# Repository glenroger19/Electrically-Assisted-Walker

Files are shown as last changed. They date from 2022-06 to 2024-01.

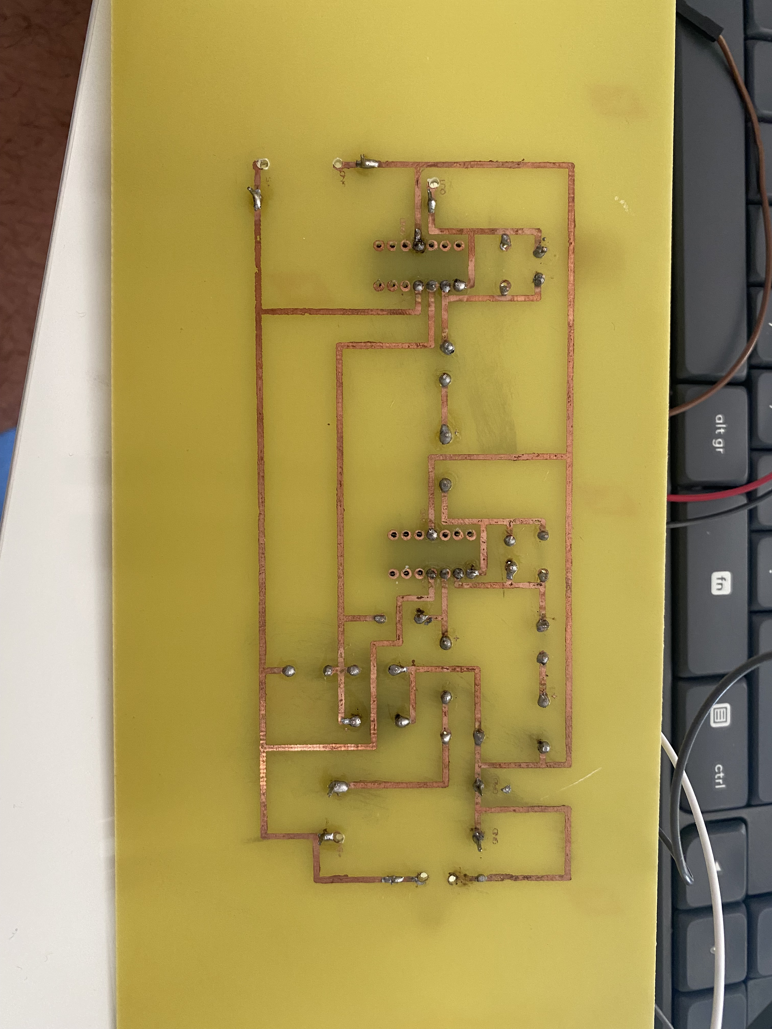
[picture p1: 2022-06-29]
Amplifier/Amplifier Back.jpg

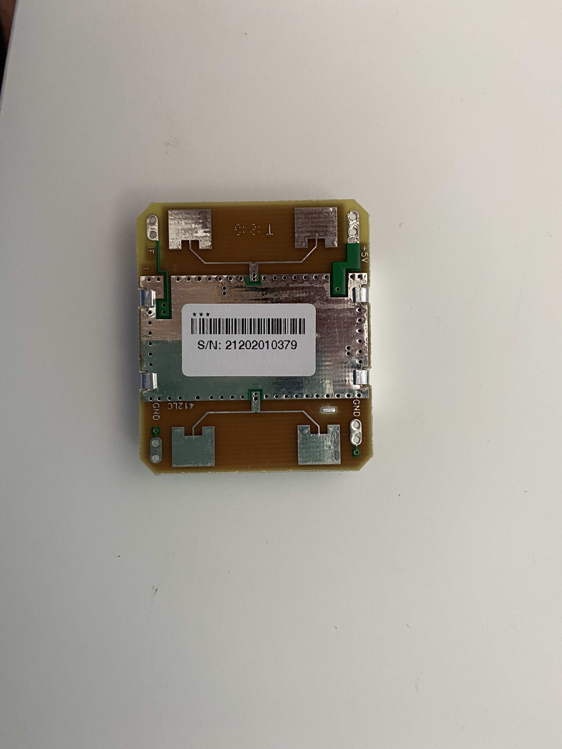
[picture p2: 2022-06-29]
Sensor/Sensor Front.jpg

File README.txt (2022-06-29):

Hi everyone, 

Welcome to this project that deals with setting up an electrically assisted walker.

Step 1 : Choose an AgilSense HB100 Doppler Sensor.
Step 2 : Amplify the signal out of the sensor which is a voltage between 0 and 4 mV.
Step 3 : Measure the voltage after amplifier which is between 0 to 4 V.
Step 4 : Use a DAC (Digital to Analog Converter) and use the code to measure the speed.
Step 5 : Perform a simulation of the motor with different resisting torque.
Step 6 : Carry out a simulation of the motor speed control and choose a corrector.
Step 7 : Vary the gain of a proportional corrector and the gain of an integral corrector to have an accurate, fast and stable system.

Thanks for your interest and hope to colaborate soon!

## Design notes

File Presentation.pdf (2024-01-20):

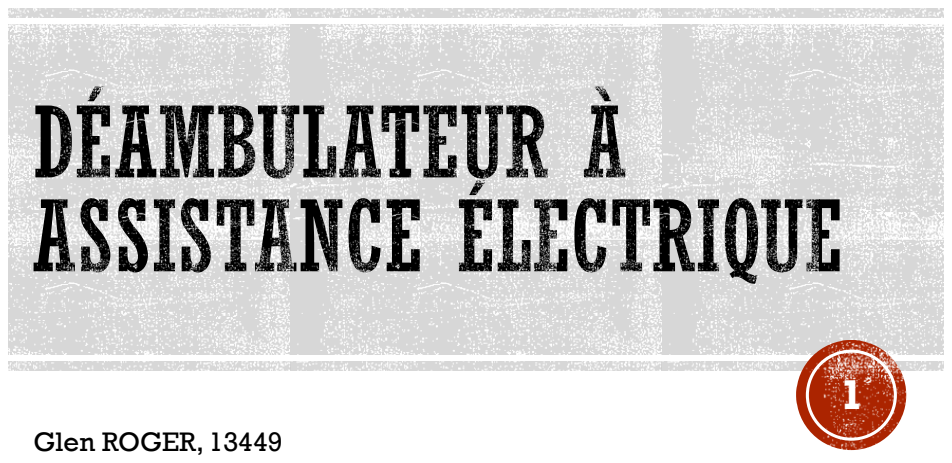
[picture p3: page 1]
Glen ROGER, 13449

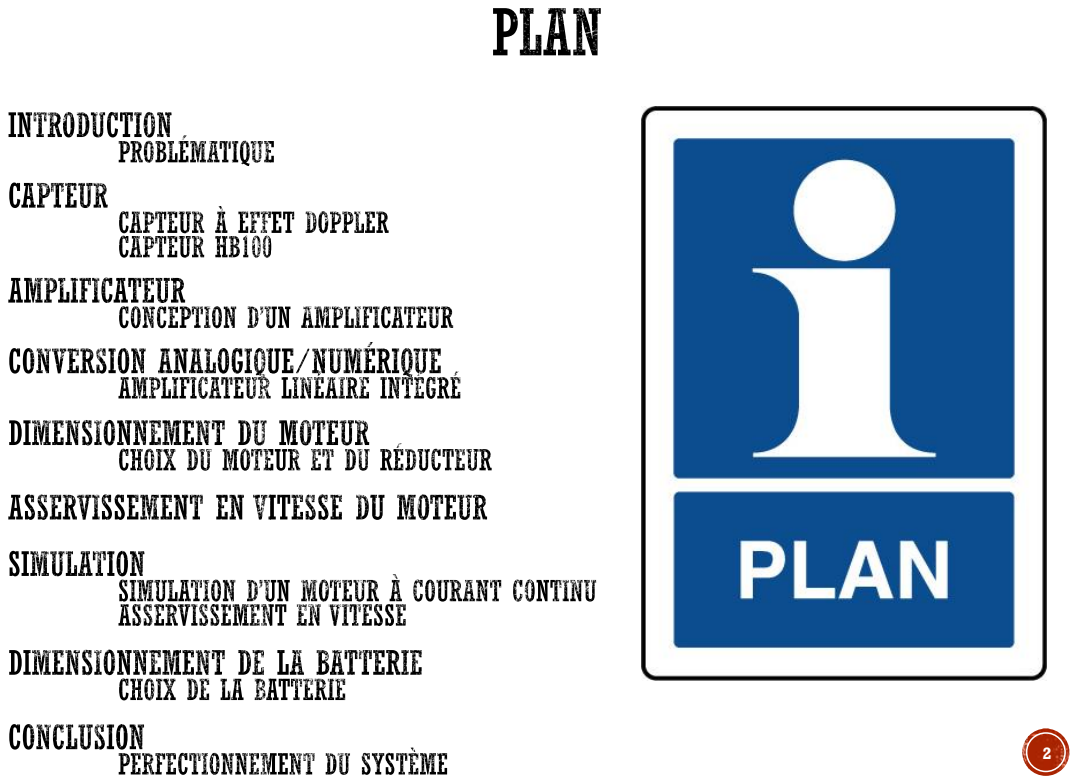
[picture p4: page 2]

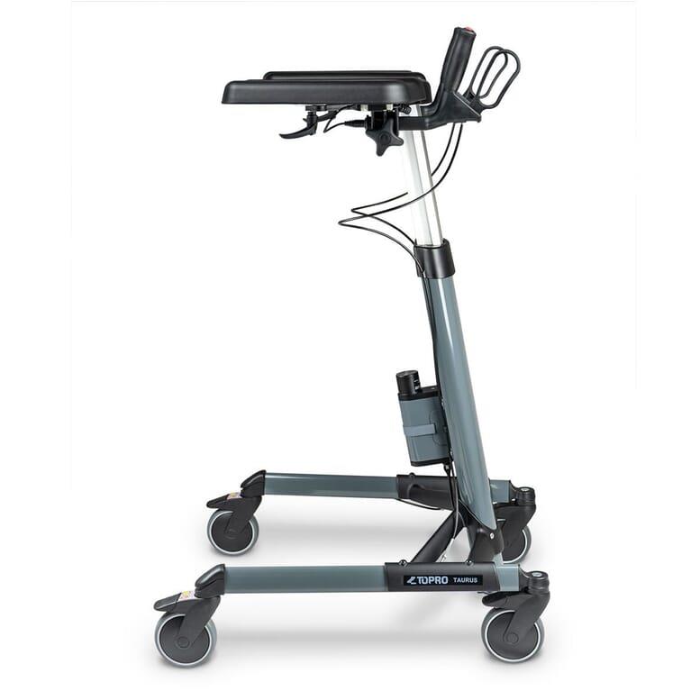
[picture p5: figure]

Source : Déambulateur Topro Taurus

3

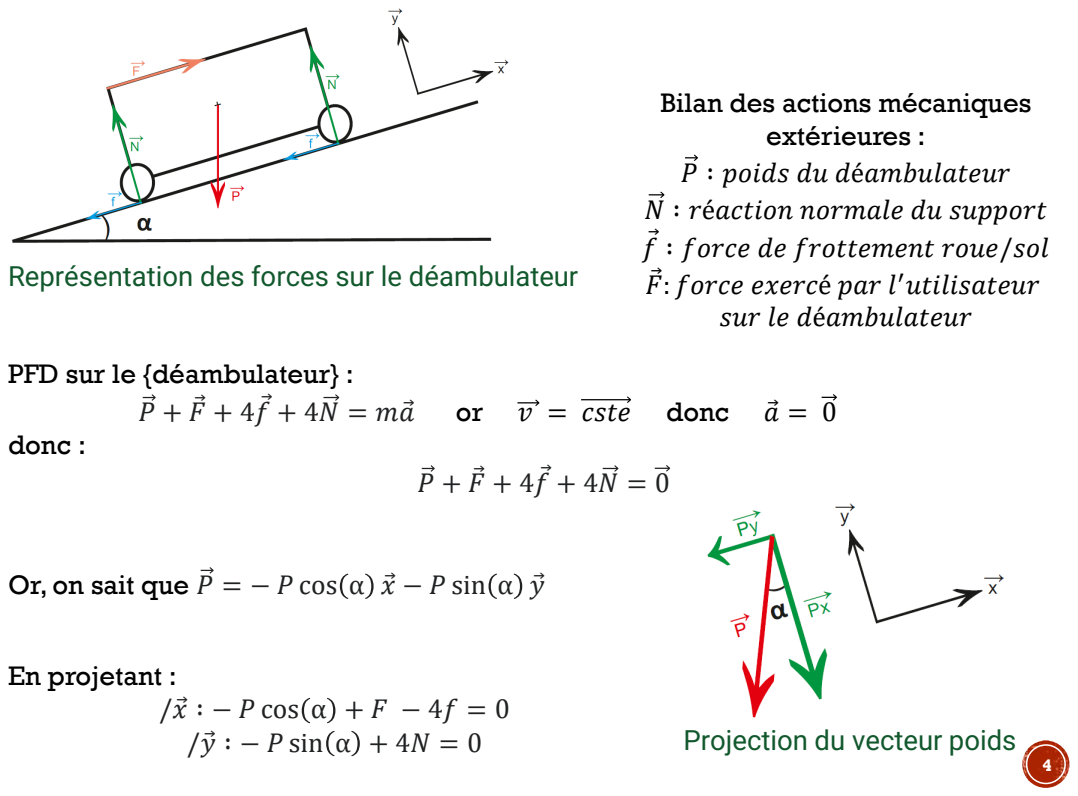
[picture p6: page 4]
extérieures : P ∶ poids du déambulateur N ∶ réaction normale du support f; ′utilisateur sur le déambulateur; v = cste; donc; donc :; Ԧ − P sin α y; En projetant : /x; ∶ − P cos α + F − 4f = 0 /y; ∶ − P sin α + 4N = 0

Bilan des actions mécaniques

∶ force de frottement roue/sol
: force exercé par l

Représentation des forces sur le déambulateur

PFD sur le {déambulateur} :

Or, on sait que P = − P cos α x

Projection du vecteur poids

Application numérique :
m = 30 kg
g = 9,81 m/s
α = 20°
μ = 0,5

On a donc :
F = 30 ∗ 9,81 ∗ cos 20 + 4 ∗ 0,5 ∗ 30 ∗ 9,81 ∗ sin 20 F = 477,9 N
Soit F ≈ 48,73 kg

On a alors :
F = P cos α + 4μ ∗ P ∗ sin α F = mg ∗ cos α + 4μ ∗ mg ∗ sin α

Or :
f = μN
avec μ ∶ coefficient de glissement Et :
N = P sin(α)
Donc :
4f = 4μ ∗ P ∗ sin(α)

5

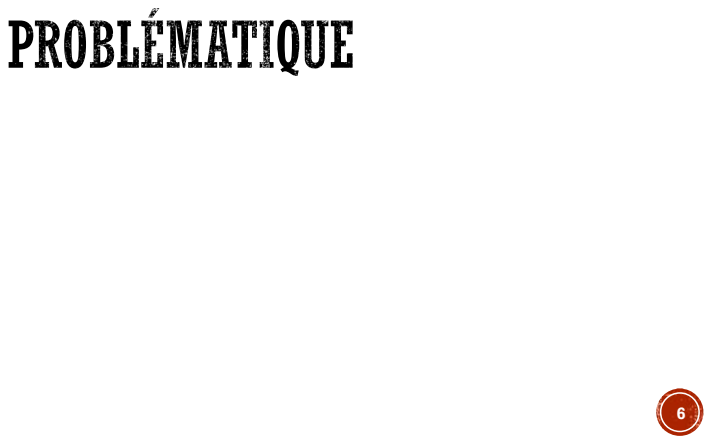
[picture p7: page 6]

7

Dispositif :
grandeur physique | tension, intensité,…

Types de capteur :

Capteurs analogiques

Capteurs logiques

Capteurs numériques

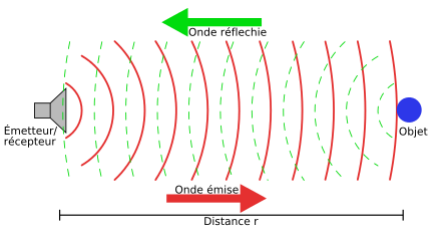
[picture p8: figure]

Source : http://www.lyc-mansart-st-cyr.ac-versailles.fr/IMG/pdf/tpevincent.pdf

8

Doppler Equation:
Fd = 2V

Ft
c

cosϴ

Avec :
Fd = Fréquence Doppler
V = Vitesse de la cible
Ft = Fréquence de transmission c = vitesse de la lumière
ϴ = Angle entre la cible et l

′axe du module

Et on a d’après le datasheet : Ft = 10,525 GHz

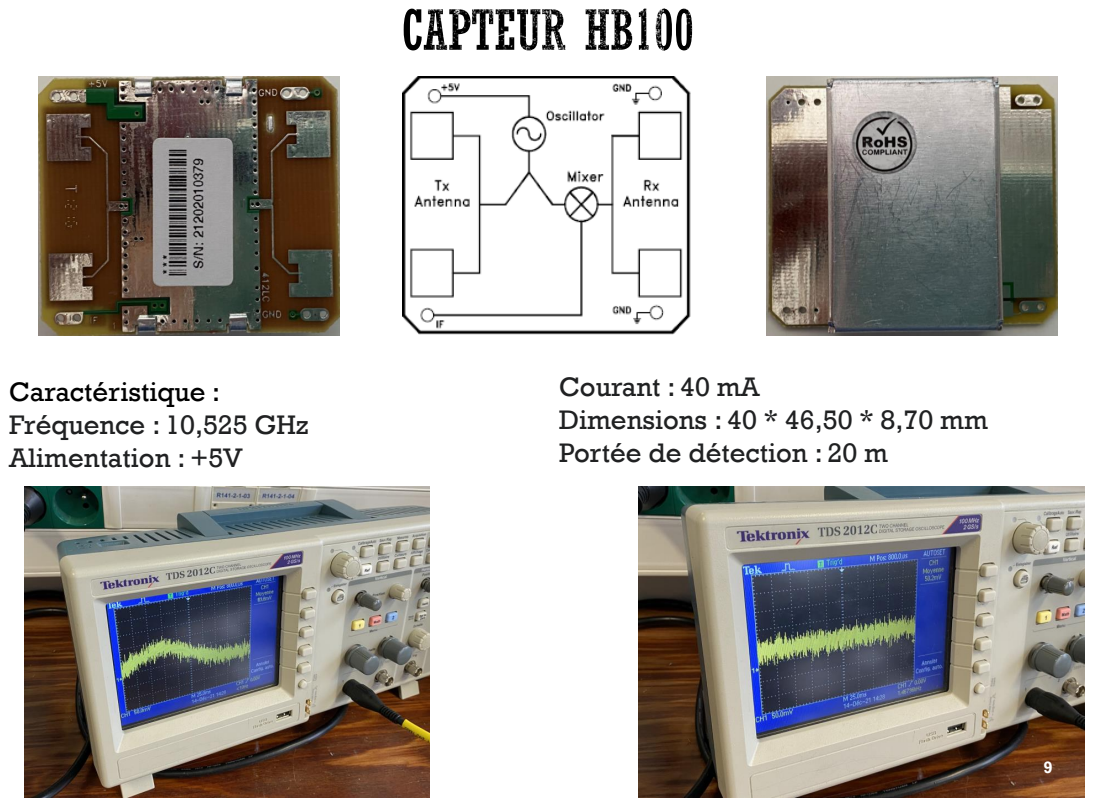
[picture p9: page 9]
Caractéristique : Fréquence : 10,525 GHz Alimentation : +5V

Courant : 40 mA
Dimensions : 40 * 46,50 * 8,70 mm
Portée de détection : 20 m

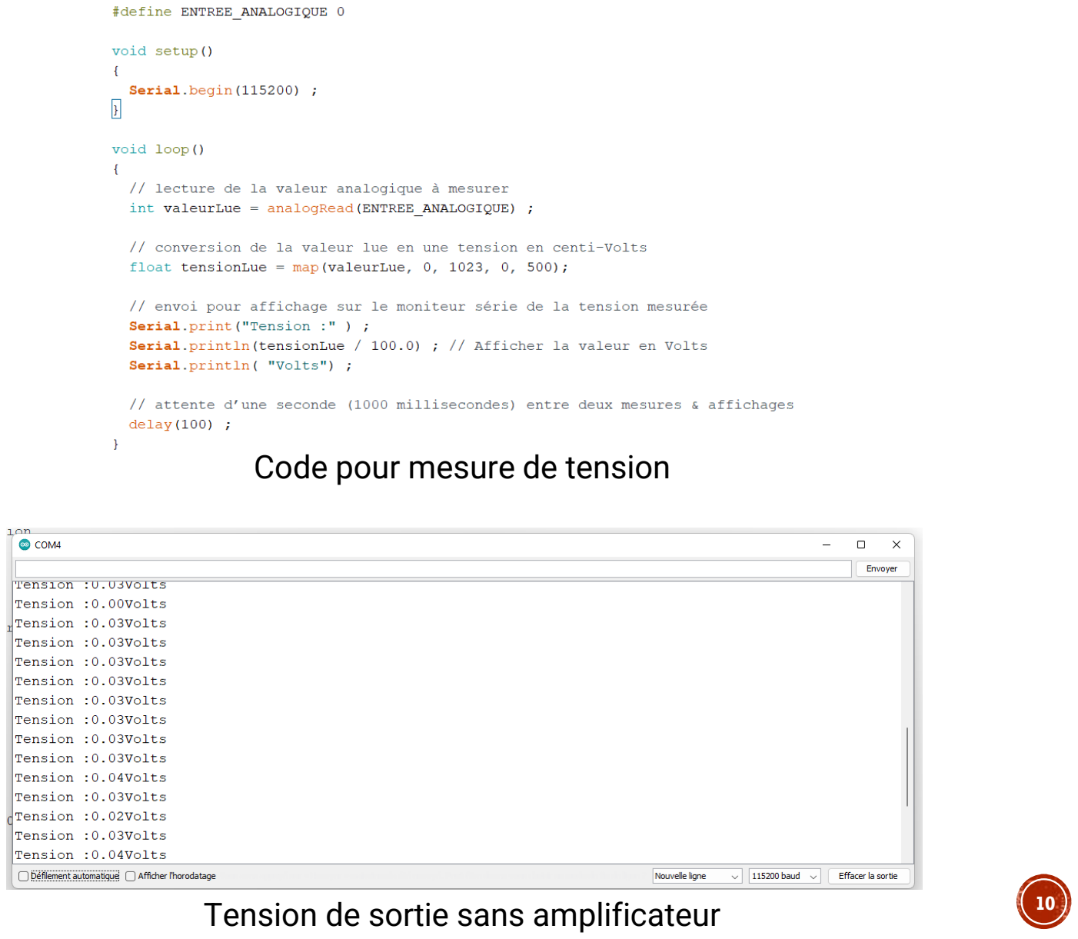
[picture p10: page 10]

Tension de sortie sans amplificateur

Code pour mesure de tension

10

- Type :

Amplificateur basse fréquence à gain élevé

- But :
Amplifier le signal
Effacer le bruit présent sur le signal

Source : HB100 datasheet

11

Typon créé à partir du logiciel TCI-4

## Essai n°2 : Par gravure chimique

Matériels :

- Plaque de cuivre PCB
- Papier glacé
- Papier abrasif
- Alcool
- Dissolvant

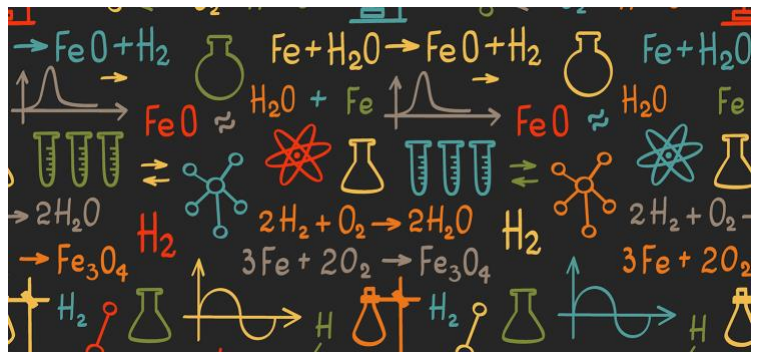
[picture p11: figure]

- Perchlorure de fer
- Acétone

Protocole :

- Imprimer le typon sur le papier glacé
- Gratter la plaque de cuivre
- Nettoyer la plaque avec de l’alcool
- Effectuer le transfert avec le dissolvant
- Laisser sécher le dissolvant
- Plonger la plaque dans du perchlorure de fer

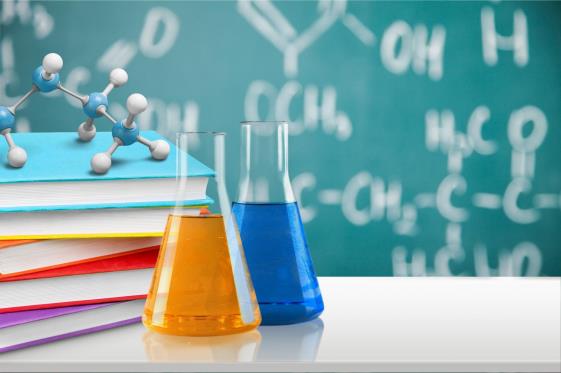
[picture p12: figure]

- Agiter pour accélérer la réaction
- Enlever l’encre avec de l’acétone

2 FeCl3 + Cu → 2 FeCl2 + CuCl2

Un peu de chimie !

13

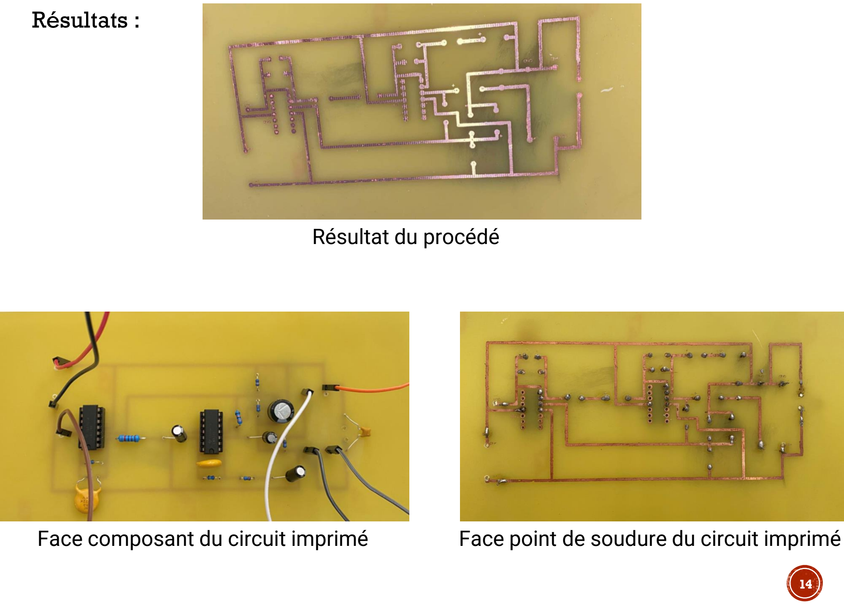
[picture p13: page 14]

Résultats :

Résultat du procédé

Face composant du circuit imprimé | Face point de soudure du circuit imprimé

14

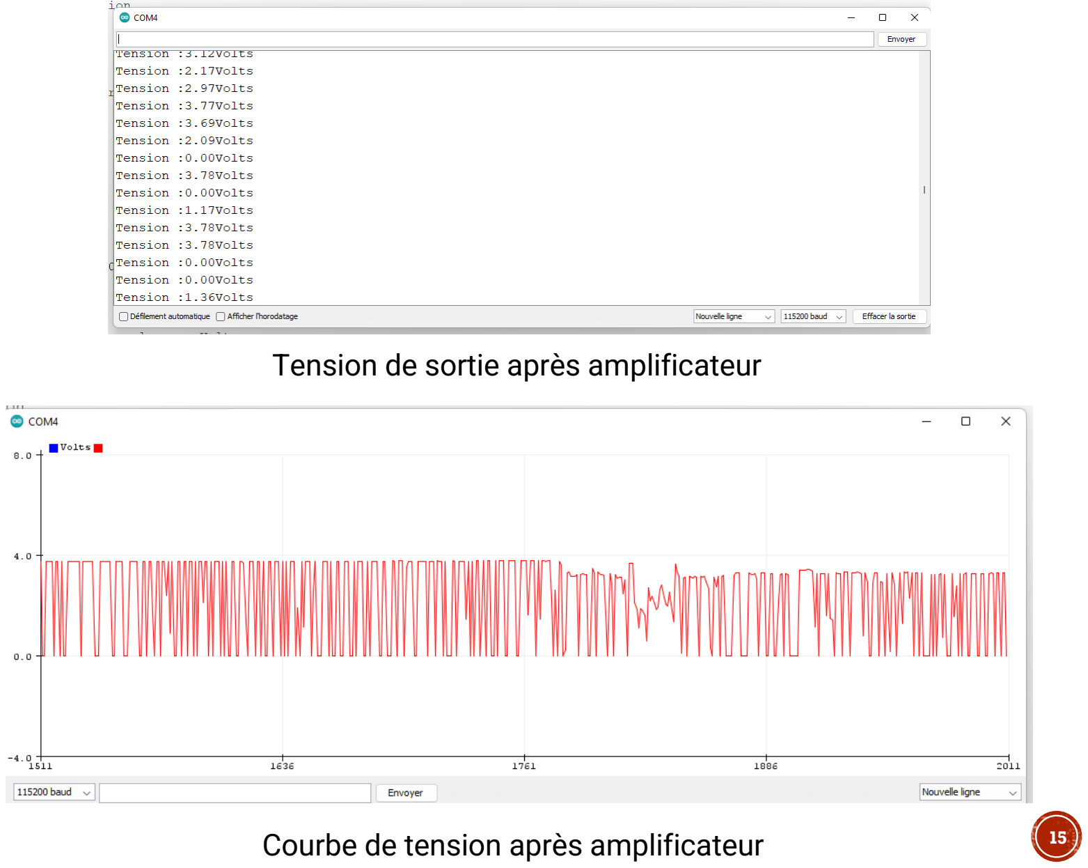
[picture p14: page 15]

Courbe de tension après amplificateur

Tension de sortie après amplificateur

15

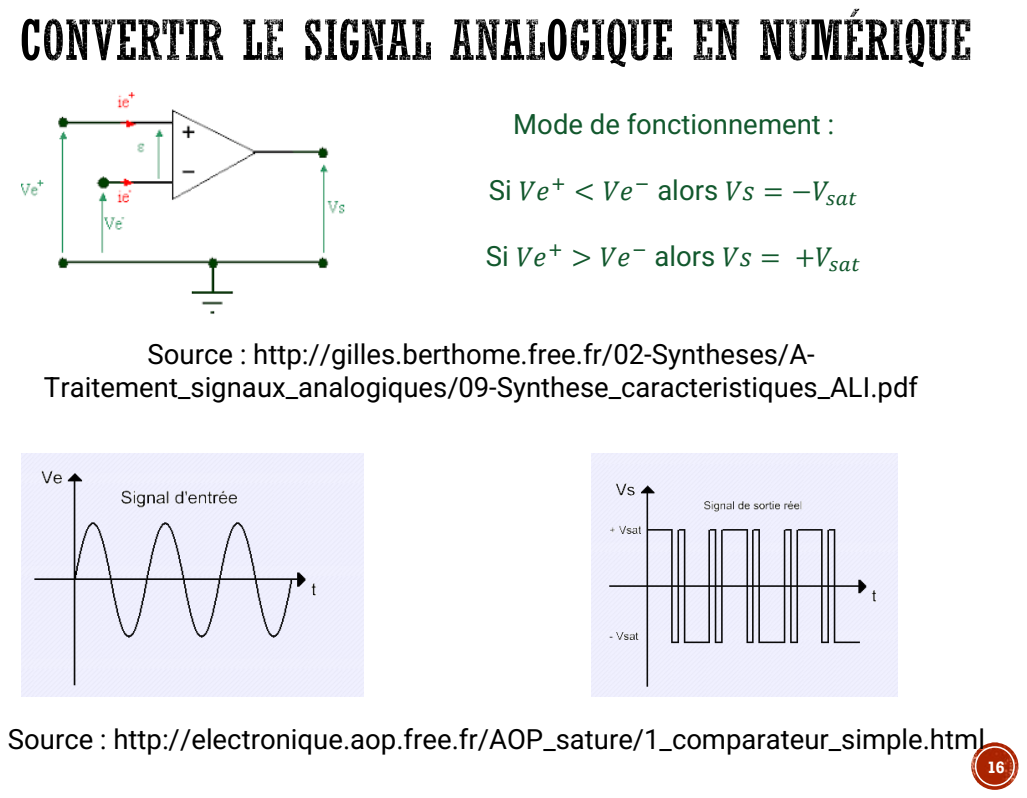
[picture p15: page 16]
Traitement_signaux_analogiques/09-Synthese_caracteristiques_ALI.pdf

Mode de fonctionnement :

Si Ve⁺ < Ve⁻ alors Vs = −Vsat

Si Ve⁺ > Ve⁻ alors Vs = +Vsat

Source : http://gilles.berthome.free.fr/02-Syntheses/A-

Source : http://electronique.aop.free.fr/AOP_sature/1_comparateur_simple.html

17

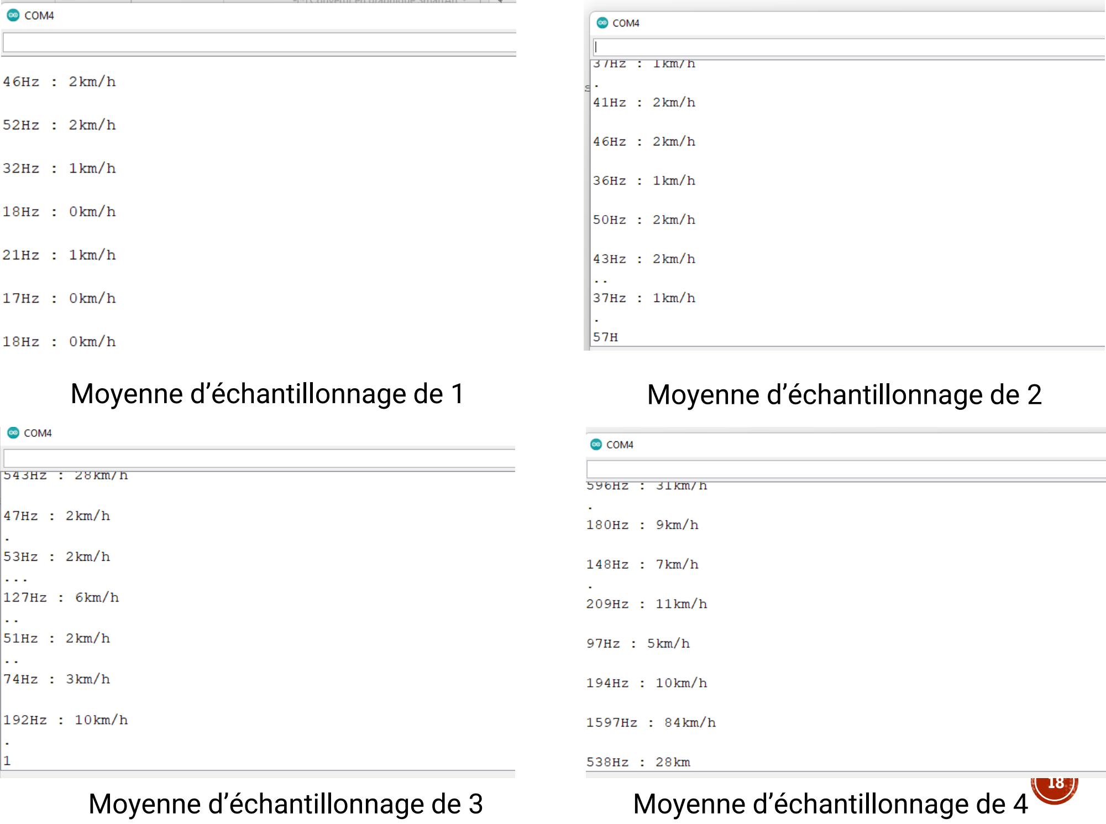
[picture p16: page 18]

Moyenne d’échantillonnage de 1 | Moyenne d’échantillonnage de 2
Moyenne d’échantillonnage de 3 | Moyenne d’échantillonnage de 4

18

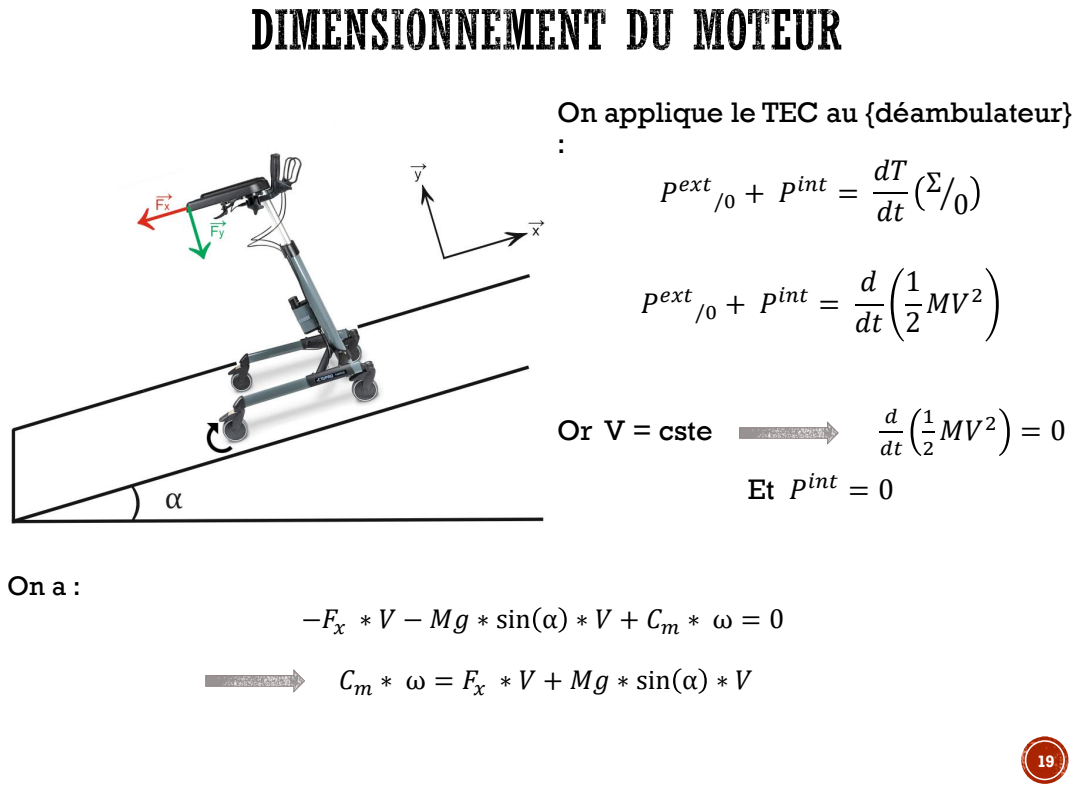
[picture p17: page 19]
ext; int =; Or V = cste; int = 0

On applique le TEC au {déambulateur}

−Fx ∗ V − Mg ∗ sin α ∗ V + Cm ∗ ω = 0

Cm ∗ ω = Fx ∗ V + Mg ∗ sin α ∗ V

Application numérique :
M = 30 kg + 100 kg
g = 9,81 m/s
α = 20°
Fx = 100 N
V = 1,5 m/s

On a donc :
P = Cm ∗ ω = 1,5 100 + 130 ∗ 9,81 ∗ sin 20 P = 804,3 W
Soit P ≈ 201, 08 W pour un seul moteur

On sait que :
| ω = 2 V
| D

Application numérique :
| D = 0,1 m
Donc :
| ω = 2 ∗ 1,5
| 0,1 = 30 rad/s

Cm =

P
ω

=

201,08
30

= 6,7 Nm
20

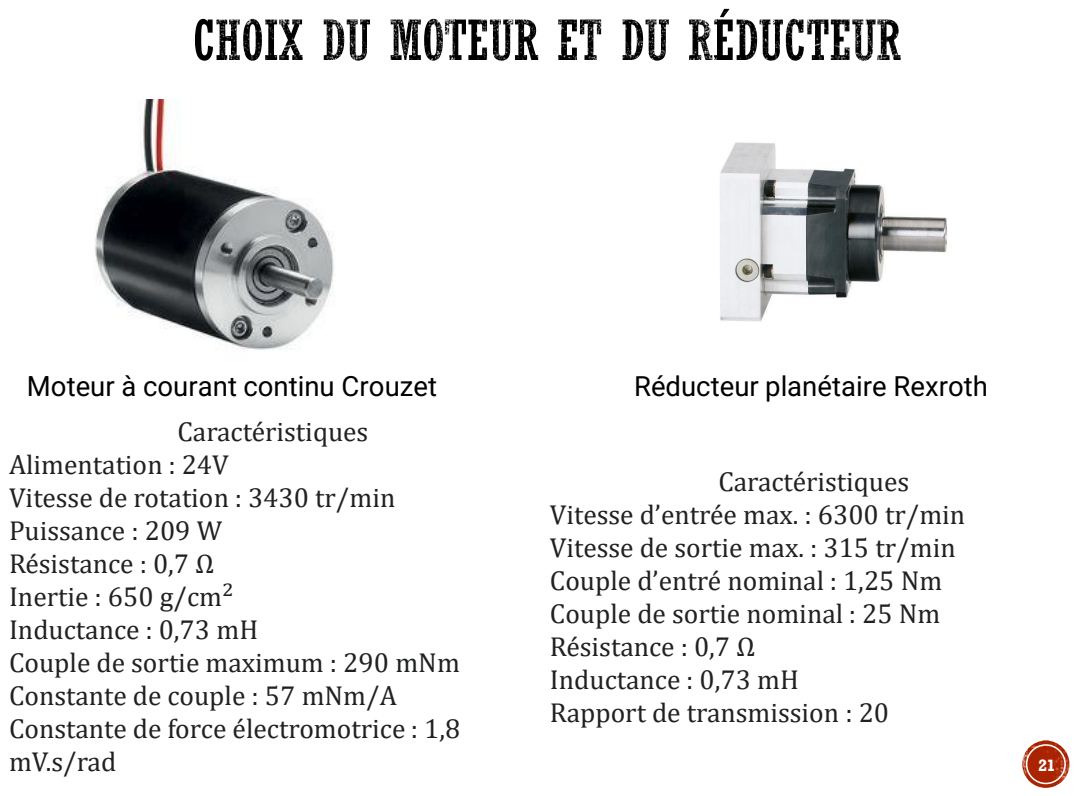
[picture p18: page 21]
Caractéristiques; Moteur à courant continu Crouzet; Réducteur planétaire Rexroth

Alimentation : 24V
Vitesse de rotation : 3430 tr/min
Puissance : 209 W
Résistance : 0,7 Ω
Inertie : 650 g/cm²
Inductance : 0,73 mH
Couple de sortie maximum : 290 mNm
Constante de couple : 57 mNm/A
Constante de force électromotrice : 1,8
mV.s/rad

Vitesse d’entrée max. : 6300 tr/min
Vitesse de sortie max. : 315 tr/min
Couple d’entré nominal : 1,25 Nm
Couple de sortie nominal : 25 Nm
Rapport de transmission : 20

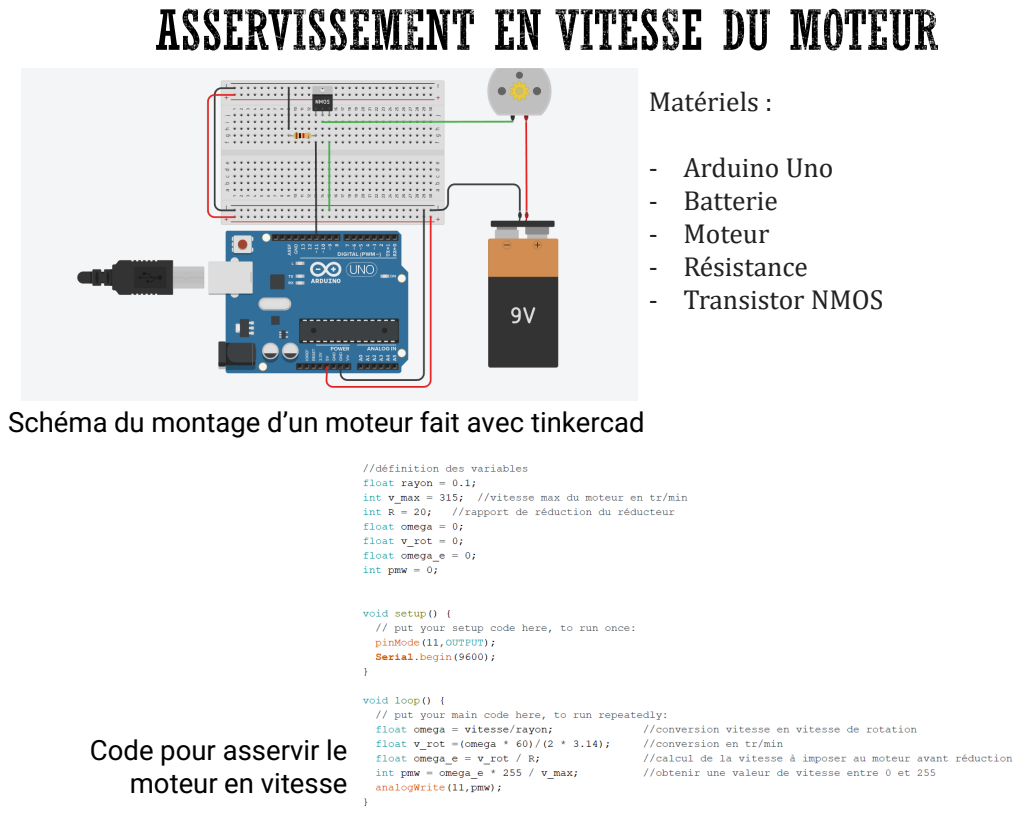
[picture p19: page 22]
Matériels :; - Arduino Uno - Batterie - Moteur - Résistance - Transistor NMOS

Schéma du montage d’un moteur fait avec tinkercad

Code pour asservir le
moteur en vitesse

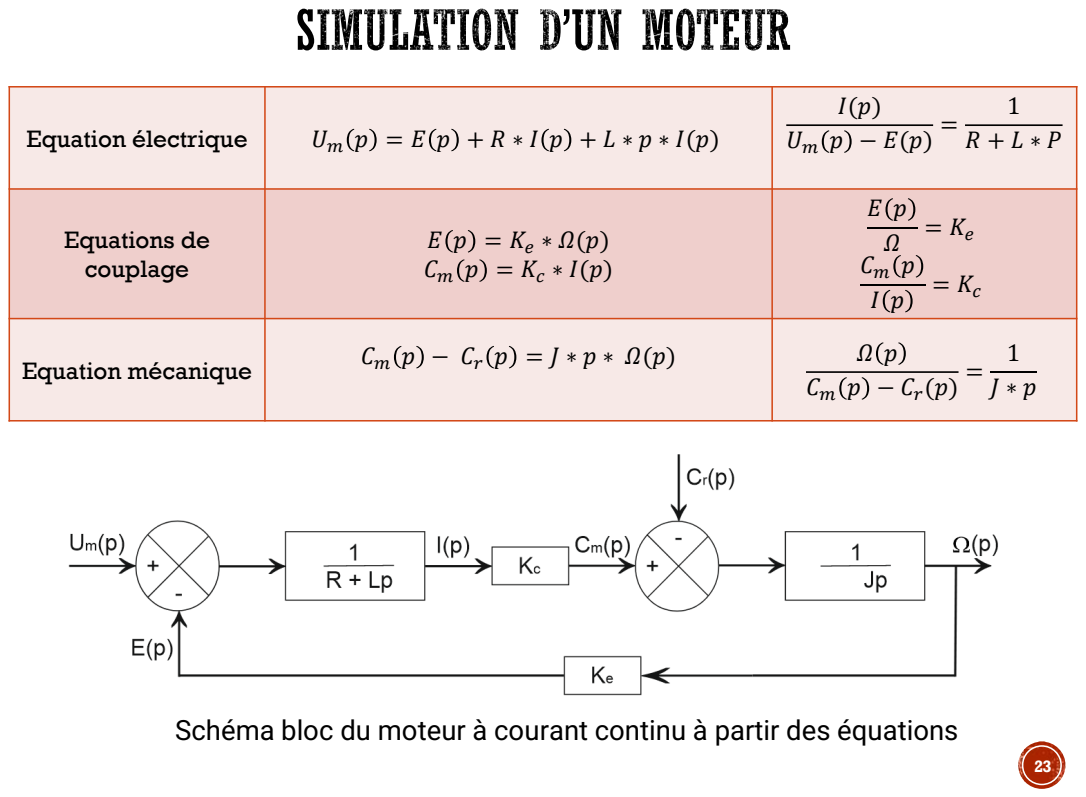
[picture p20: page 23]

Equation électrique | Um p = E p + R ∗ I p + L ∗ p ∗ I(p) | I(p) 1 = Um p − E(p) R + L ∗ P

Equations de couplage | E p = Ke ∗ Ω(p) Cm p = Kc ∗ I(p) | E p = Ke Ω Cm p = Kc I p

Equation mécanique | Cm p − Cr p = J ∗ p ∗ Ω(p) | Ω p 1 = Cm p − Cr(p) J ∗ p

Schéma bloc du moteur à courant continu à partir des équations

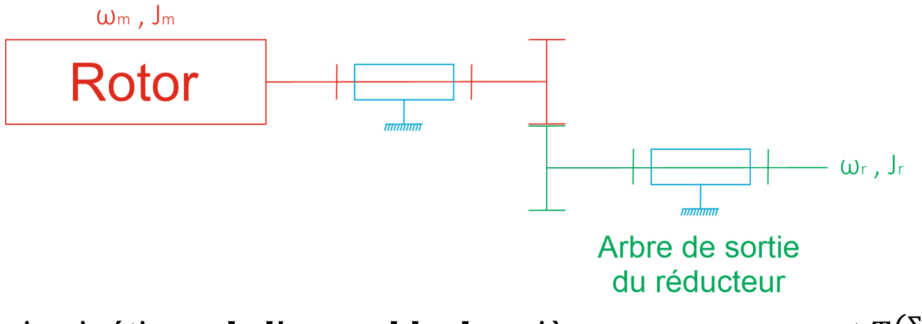
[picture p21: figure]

Energie cinétique de l’ensemble des pièces en mouvement T ൗ

Σ
R0
On a :

T ൗ

Σ
R0

=

1
2

Jmωm

2 +

1
2

Jrωr

2

Soit :

T ൗ

Σ
R0

=

1
2

Jmωm

2 +

1
2

ωr

ωm

2
Jrωm

2

Donc :

T ൗ

Σ
R0

=

1
2

Jm + R

2
Jr ωm
2 | avec R =

ωr

ωm

rapport de transmission

On identifie ainsi :
J = Jm + R

2
Jr
Application numérique : | J = 6,5 ∗ 10⁻⁵ + 20²

∗ 1,2 ∗ 10⁻⁵

J = 4,9 ∗ 10⁻³ kg/m² | 24

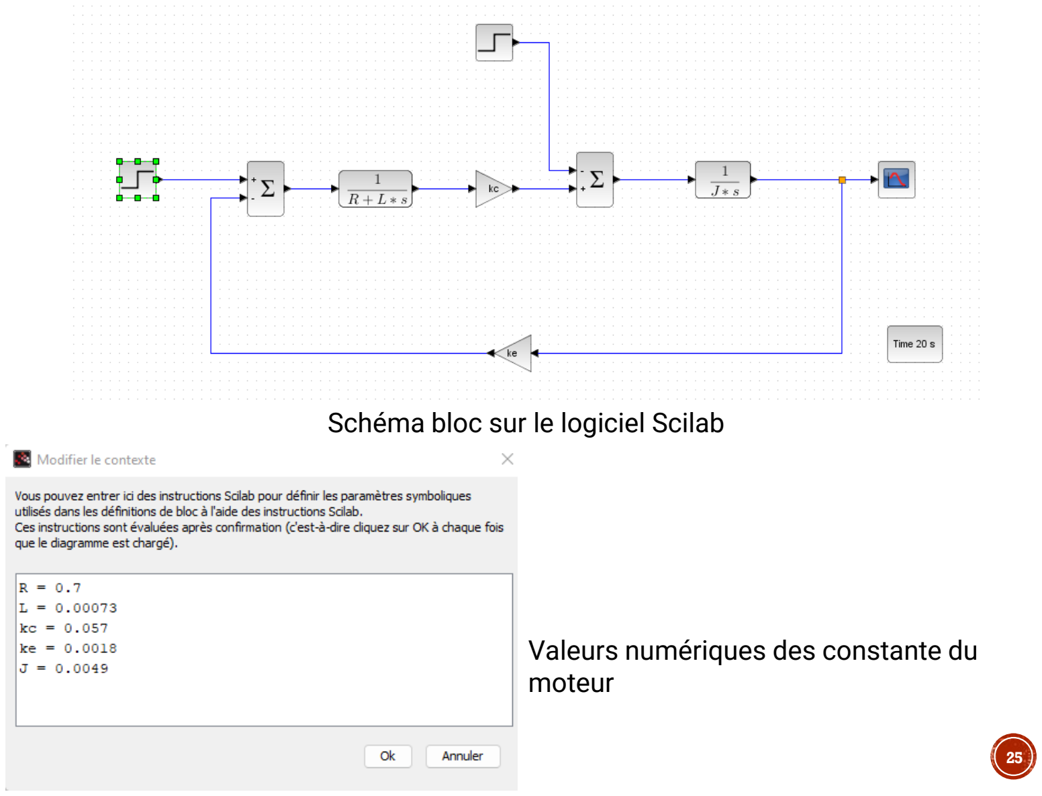
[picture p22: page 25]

Schéma bloc sur le logiciel Scilab

Valeurs numériques des constante du moteur

25

Courbe avec une consigne de 10 V et sans perturbation

Caractéristiques
Valeur finale : 5500 rad/s Temps de réponse à 5% : 0,43s Gain statique : 550 rad/s/V

Courbe une consigne de 10 V et une perturbation de 0,05 Nm avec un échelon retardé de 10 secondes

Caractéristiques
Valeur finale : 5214,5 rad/s Temps de réponse à 5% : 0,39s Gain statique : 521,45 rad/s/V

26

On adopte pour la suite la modélisation suivante :

Schéma bloc de l’asservissement en vitesse

Simulation avec le logiciel Scilab et les données du moteur

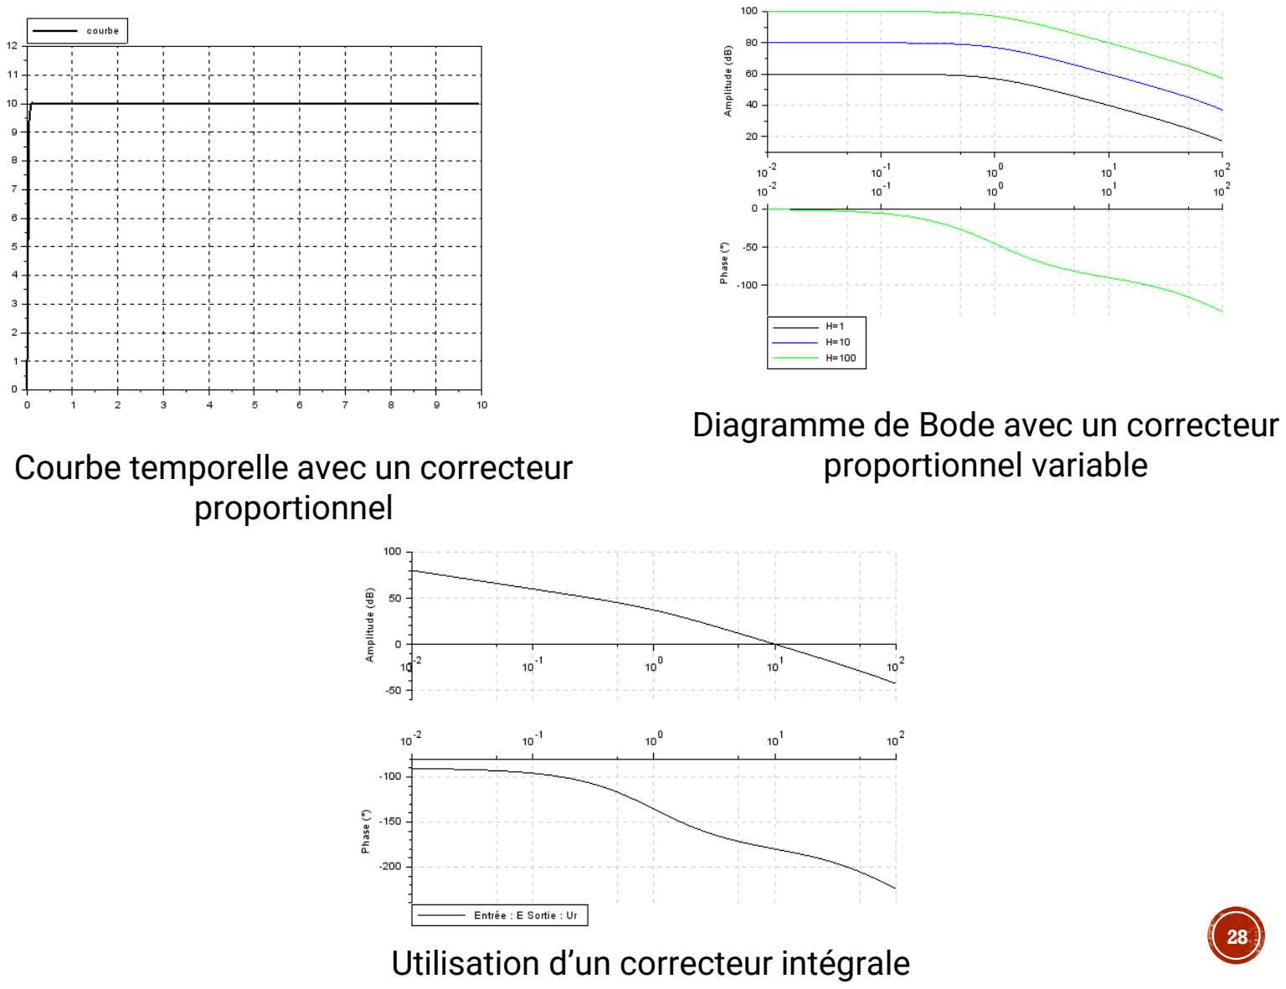
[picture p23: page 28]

Utilisation d’un correcteur intégrale

Courbe temporelle avec un correcteur proportionnel

Diagramme de Bode avec un correcteur proportionnel variable

28

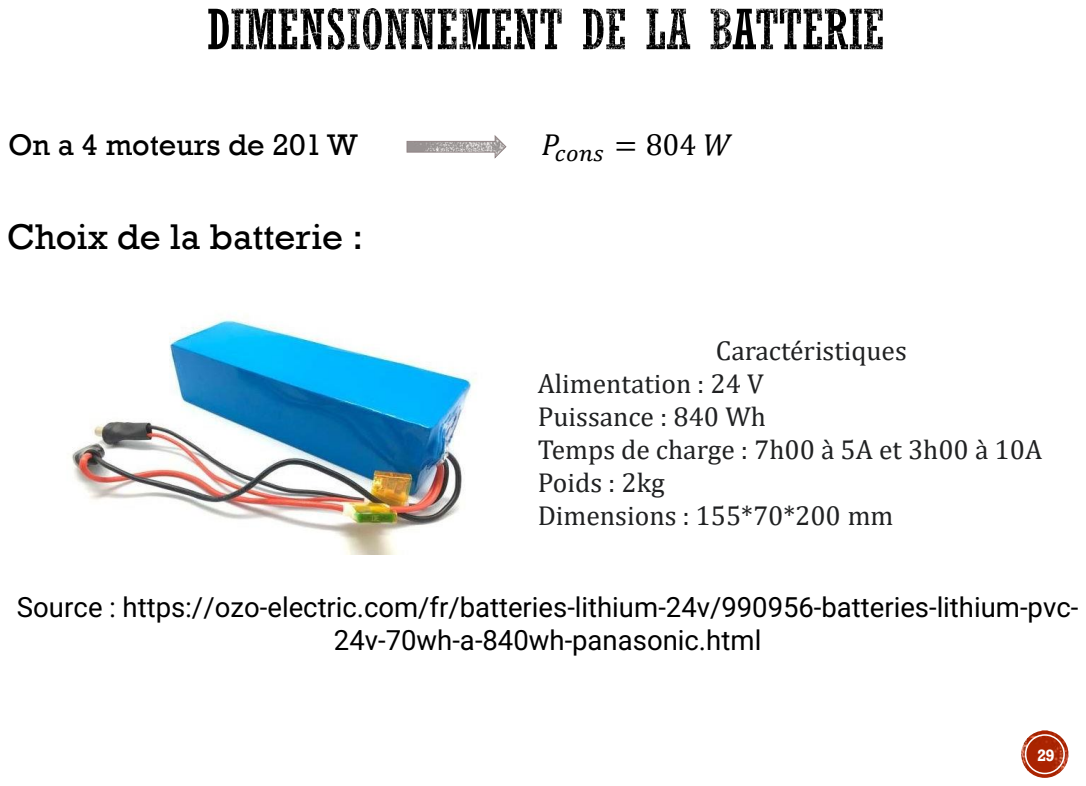
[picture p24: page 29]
On a 4 moteurs de 201 W; Pcons = 804 W; Caractéristiques; 24v-70wh-a-840wh-panasonic.html

Choix de la batterie :

Alimentation : 24 V
Puissance : 840 Wh
Temps de charge : 7h00 à 5A et 3h00 à 10A
Poids : 2kg
Dimensions : 155*70*200 mm

Source : https://ozo-electric.com/fr/batteries-lithium-24v/990956-batteries-lithium-pvc-

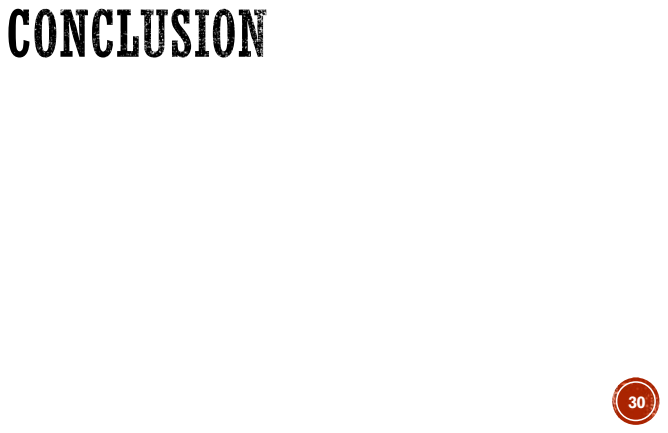
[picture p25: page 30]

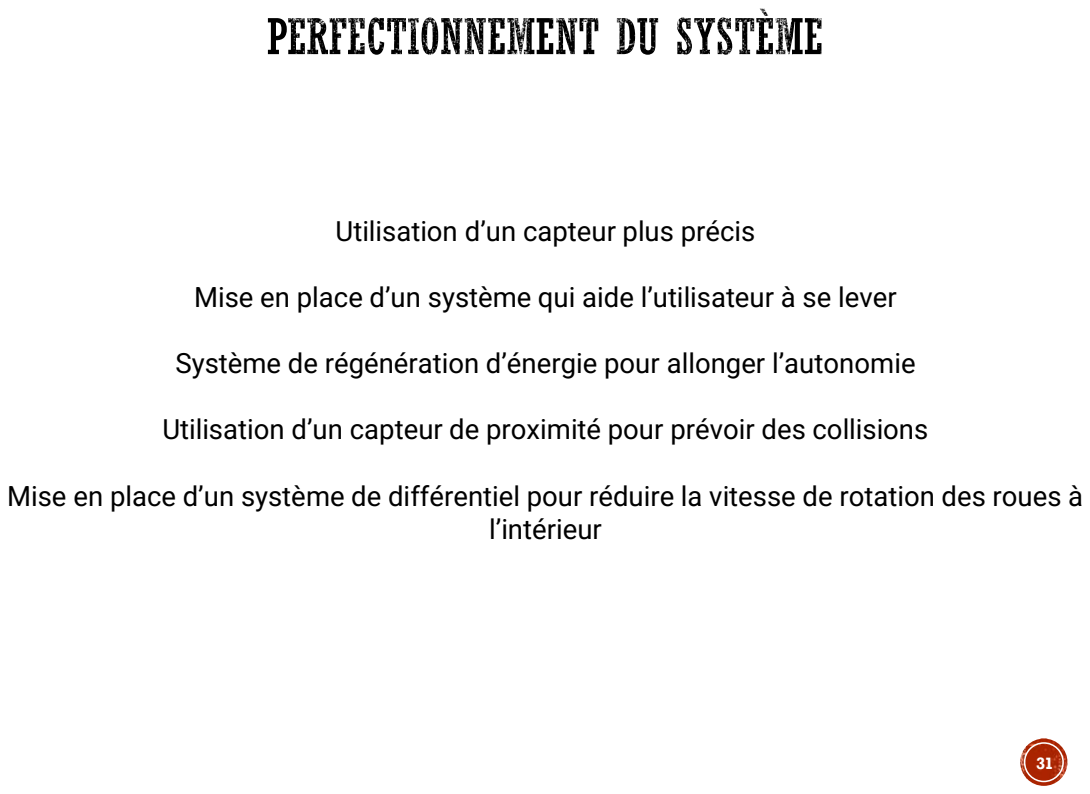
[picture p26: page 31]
l’intérieur

Utilisation d’un capteur plus précis

Mise en place d’un système qui aide l’utilisateur à se lever

Système de régénération d’énergie pour allonger l’autonomie

Utilisation d’un capteur de proximité pour prévoir des collisions

Mise en place d’un système de différentiel pour réduire la vitesse de rotation des roues à

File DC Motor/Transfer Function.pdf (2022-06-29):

+

1
R + Lp

K
c

+

1
f + Jp

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
→Um(p)

E(p)

I(p)

C

m(p)

C

r(p)

(p)

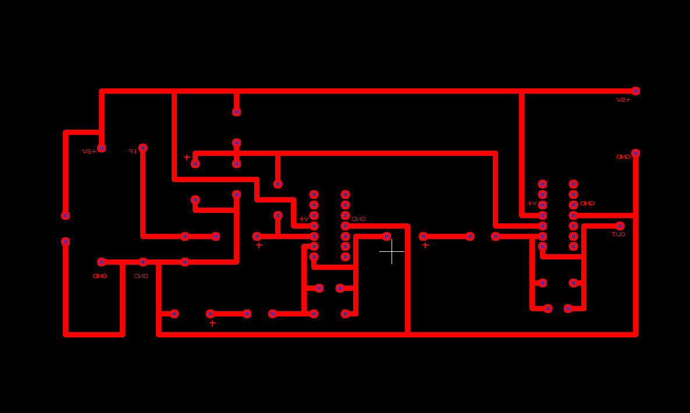
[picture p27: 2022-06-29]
Amplifier/Typon.png

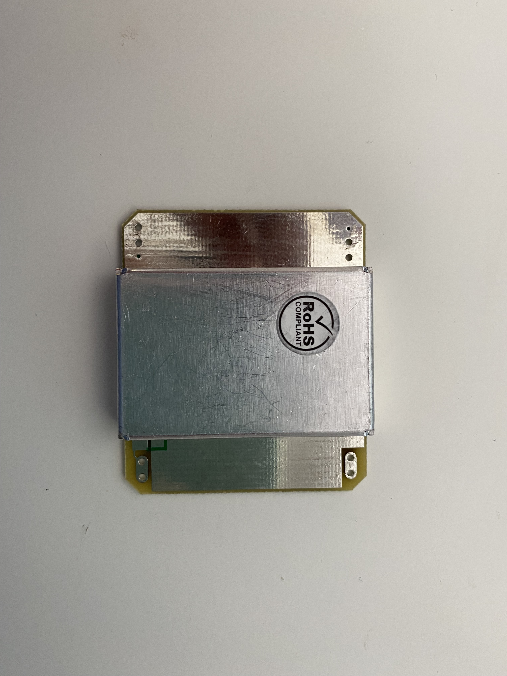
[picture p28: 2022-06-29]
Sensor/Sensor Back.jpg

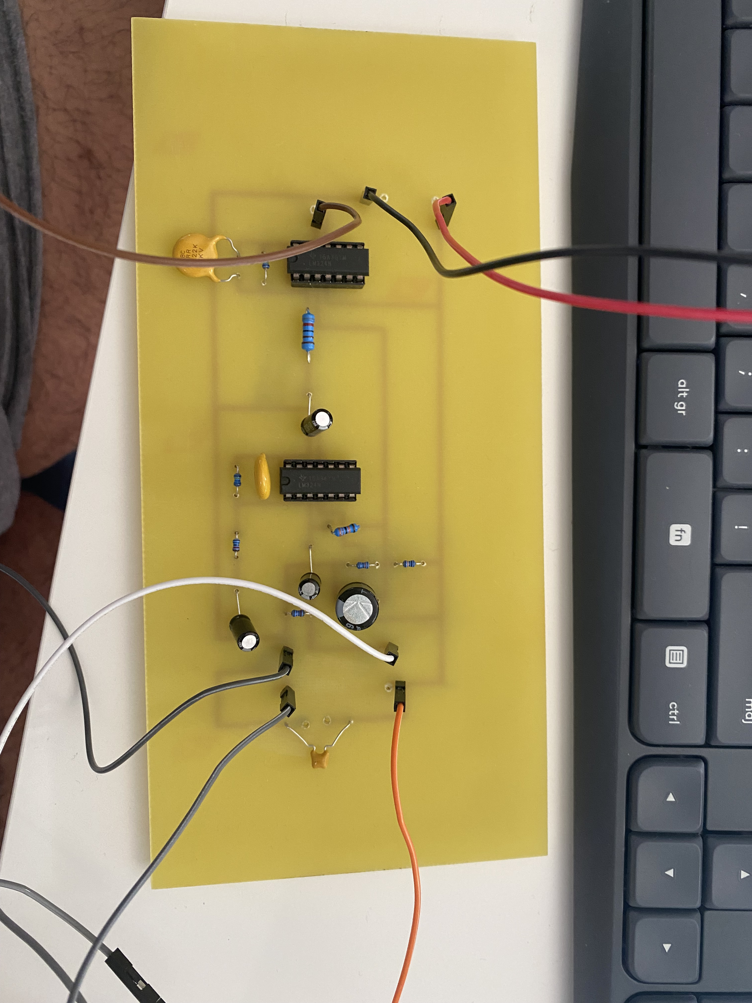
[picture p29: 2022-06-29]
Amplifier/Amplifier Front.jpg

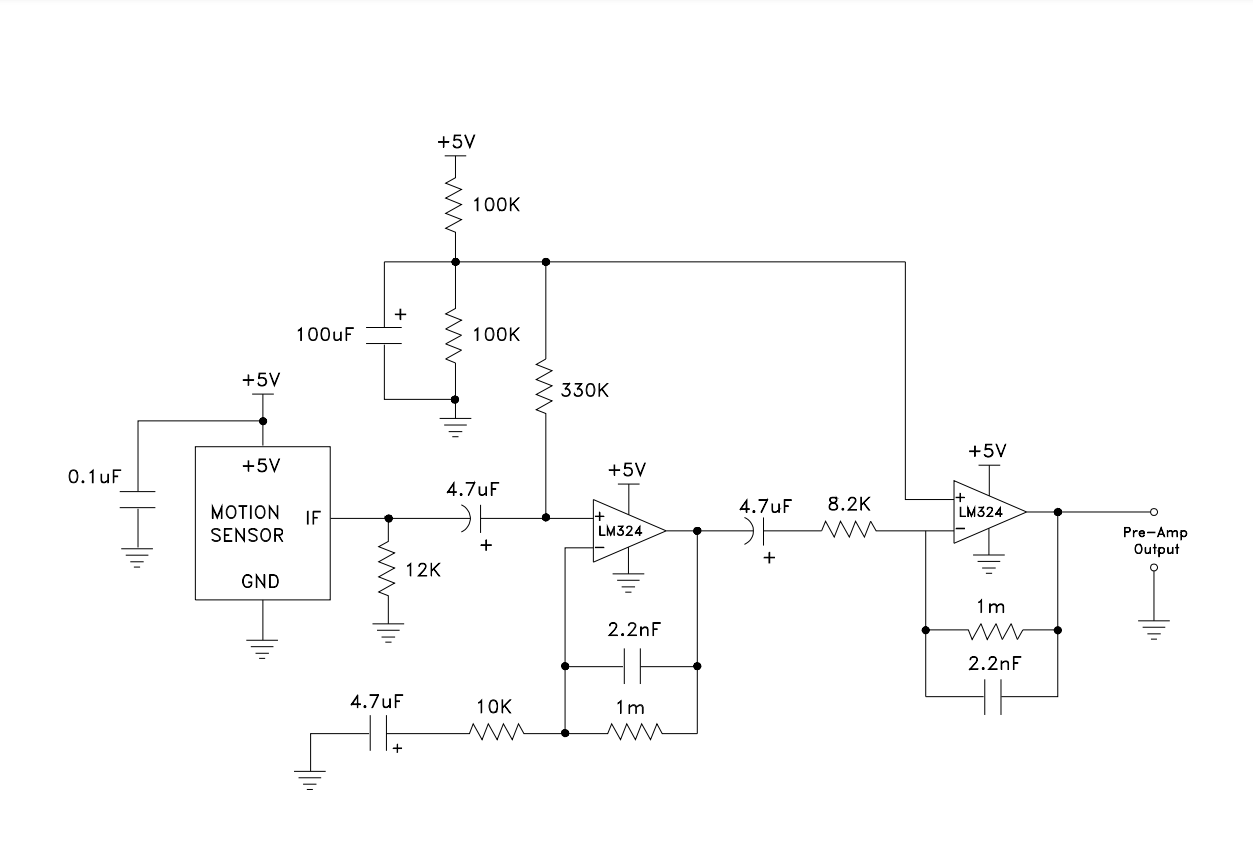
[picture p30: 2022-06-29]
Amplifier/Amplifier Circuit.png

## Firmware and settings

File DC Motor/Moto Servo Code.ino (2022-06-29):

//définition des variables
float rayon = 0.1;
int v_max = 315;  //vitesse max du moteur en tr/min
int R = 20;   //rapport de réduction du réducteur
float omega = 0;
float v_rot = 0;
float omega_e = 0;
int pmw = 0;


void setup() {
  // put your setup code here, to run once:
  pinMode(11,OUTPUT);
  Serial.begin(9600);
}

void loop() {
  // put your main code here, to run repeatedly:
  float omega = vitesse/rayon;              //conversion vitesse en vitesse de rotation
  float v_rot =(omega * 60)/(2 * 3.14);     //conversion en tr/min
  float omega_e = v_rot / R;                //calcul de la vitesse à imposer au moteur avant réduction
  int pmw = omega_e * 255 / v_max;          //obtenir une valeur de vitesse entre 0 et 255
  analogWrite(11,pmw);

}

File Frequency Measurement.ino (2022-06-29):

// Below: pin number for FOUT
#define PIN_NUMBER 4
// Below: number of samples for averaging
#define AVERAGE 4
// Below: define to use serial output with python script
//#define PYTHON_OUTPUT
unsigned int doppler_div = 19;
unsigned int samples[AVERAGE];
unsigned int x;

void setup() {
  Serial.begin(9600);
  pinMode(PIN_NUMBER, INPUT);
}

void loop() {
  noInterrupts();
  pulseIn(PIN_NUMBER, HIGH);
  unsigned int pulse_length = 0;
  for (x = 0; x < AVERAGE; x++)
  {
    pulse_length = pulseIn(PIN_NUMBER, HIGH); 
    pulse_length += pulseIn(PIN_NUMBER, LOW);    
    samples[x] =  pulse_length;
  }
  interrupts();

  // Check for consistency
  bool samples_ok = true;
  unsigned int nbPulsesTime = samples[0];
  for (x = 1; x < AVERAGE; x++)
  {
    nbPulsesTime += samples[x];
    if ((samples[x] > samples[0] * 2) || (samples[x] < samples[0] / 2))
    {
      samples_ok = false;
    }
  }

  if (samples_ok)
  {
    unsigned int Ttime = nbPulsesTime / AVERAGE;
    unsigned int Freq = 1000000 / Ttime;

    #ifdef PYTHON_OUTPUT
      Serial.write(Freq/doppler_div);
    #else
      //Serial.print(Ttime);
      Serial.print("\r\n");
      Serial.print(Freq);
      Serial.print("Hz : ");
      Serial.print(Freq/doppler_div);
      Serial.print("km/h\r\n");
    #endif
  }
  else
  {
    #ifndef PYTHON_OUTPUT
      Serial.print(".");
    #endif
  }
}
